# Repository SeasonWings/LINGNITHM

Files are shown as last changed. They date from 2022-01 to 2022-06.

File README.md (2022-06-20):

# LINGNITHM
个人记录向半开源CHUNITHM风格音乐游戏控制器

# 如果需要制作本控制器，你大体需要以下能力
* 完善的文件处理能力，可以阅读并看懂包括但不限于CAD，STP，Gerber等文件的作用
* 一定的单片机知识，能够识别和使用BootLoader和固件bin文件
* 一定的动手能力，能完成包括但不限于拧螺丝，贴片焊接，调试硬件等能力

# 控制器构成
* 控制器基于Arduino IDE，使用第三方的platfromIO编写固件程序
* 电路主控芯片使用了ATMEGA SAMD21G18A MCU，触摸IC使用了MPR121，AIR抬手感应使用了940MM红外对射灯珠
* 基本连接思路为 主控板-触摸板   主控板-AIR发射/接收转接器-HDMI线材-AIR发射/接收

如图所示
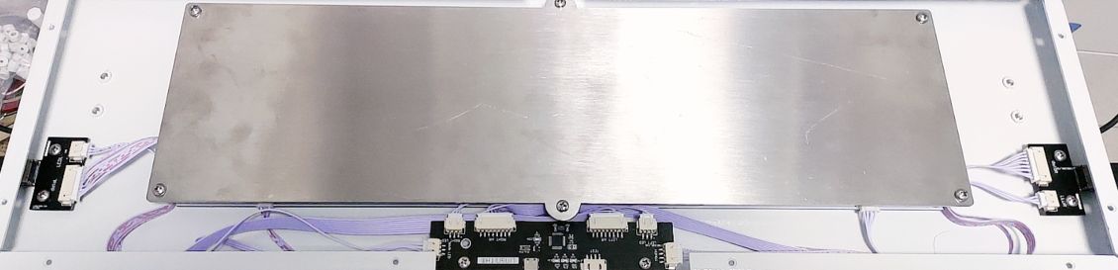
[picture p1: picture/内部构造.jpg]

                
* [固件方面](https://github.com/SeasonWings/LINGNITHM/tree/main/BootLoader%26Firmware) 有参考GSK，XPENG，ilufang，Sucareto等大佬的代码，在此特别提出感谢！！！
* 上传方面 你需要购买Jlink上传器，通过SEGGER软件向SAMD21上传固件以及BootLoader
* [物料方面](https://github.com/SeasonWings/LINGNITHM/blob/main/PCB%20Gerber%E5%88%B6%E7%89%88%E6%96%87%E4%BB%B61.1/PCB%E7%89%A9%E6%96%99BOM%E8%A1%A8.xlsx) 请在制作完PCB之后自行对照丝印(此句划掉，现在有了)

其余方面想到再补充(

# Update

#### 1.0更新
  * 脱胎换骨！现在你可以使用金属化的控制器外壳了！
  * 新的PCB设计改动以适配新的外壳。
  * 新的固件，包含直连协议(需要配合[修改后的chuniio和Segatools.ini](https://github.com/SeasonWings/LINGNITHM/tree/main/BootLoader%26Firmware/1.0%20Ver/chuniio%26Segatools "请务必将你的控制器设备放在COM1端口上！")使用),以及更加炫酷的灯光，更优的触摸算法。
  * 最新最热PCB物料BOM表已更新，感谢群友海腾的帮助！

#### 2.0更新
  * 通过上传新的固件&BootLoader来获得更新功能！
  * 键盘模式下新增设置接口，同时遮挡2，4，6号Air即可进入设置模式
  * 新增设置模式下的操作逻辑，稍后使用PDF文件进行说明
  * 现在你可以为你的键盘以及Air灯光效果自由编辑喜欢的灯光样式啦！

#### 3.0更新
  * LINGCON Setting的操作UI有部分变动
  * Setting进入逻辑修改，改变为全押Air

### 久违的更新（
#### 4.0更新
  * 代码触摸逻辑有大幅改动，现在触摸或许会更灵敏了(?)
  * Setting新增触摸校准（黄色按钮），把手指用你认为最小的力度划过触摸区来完成校准
  * 改变了新的上传Firmware方式，现在更加方便了,旧固件停止维护
  * 同时公开部分底层源代码，有能人士可以按自己所需添加想要的功能，详情见Source code

# License
CC
  * 你可以在遵循CC协议的条件下自由修改，查看，下载，使用本项目内文件
  * 禁止进行一切商业行为（“商业行为”指一切涉及本项目资金流动，包括但不限于：直接clone本项目文件 不经任何修改 拿来以任何方式出售或牟利的行为）
  * 最终解释权归本人所有
# 外观展示
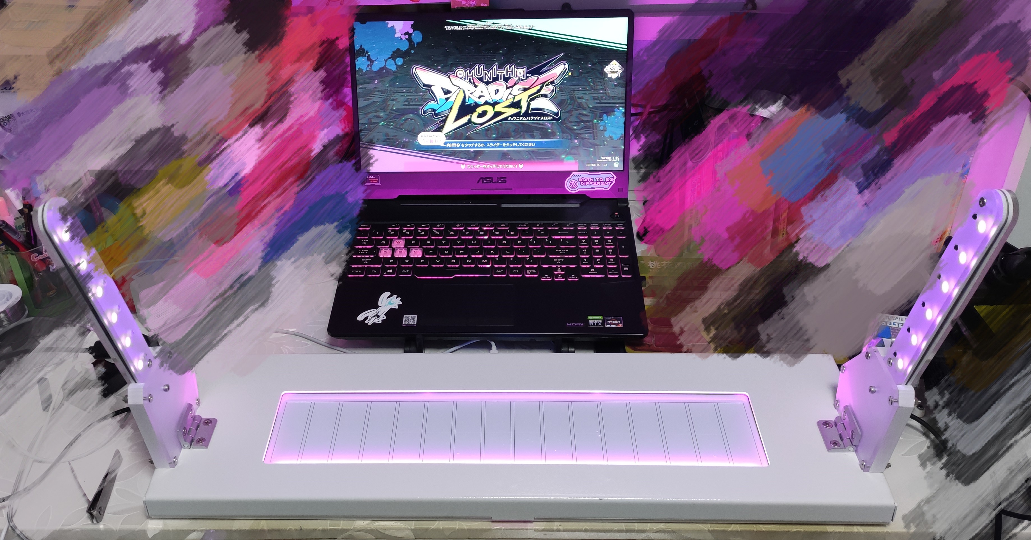
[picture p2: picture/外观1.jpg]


# 控制器使用展示
[点击这里！](https://www.bilibili.com/video/BV1Qm4y1Z7ms/ "你会给两个圆圆的硬币对么？")

如果觉得非常棒，可以给我一个一键三连么(

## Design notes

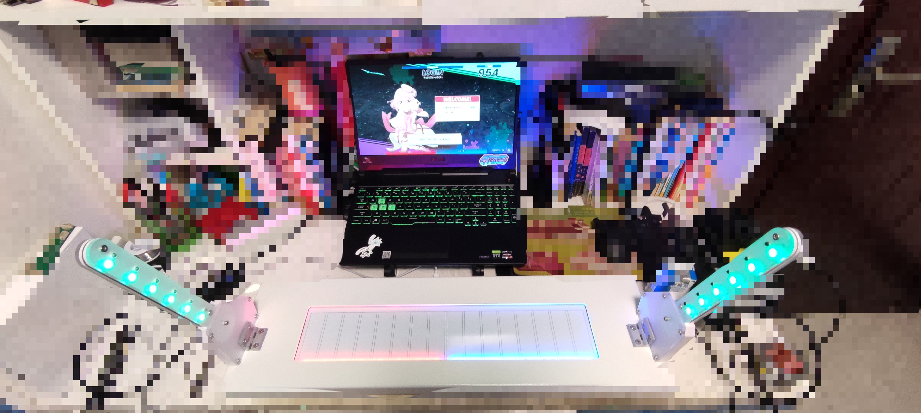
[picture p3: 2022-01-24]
picture/外观3.jpg

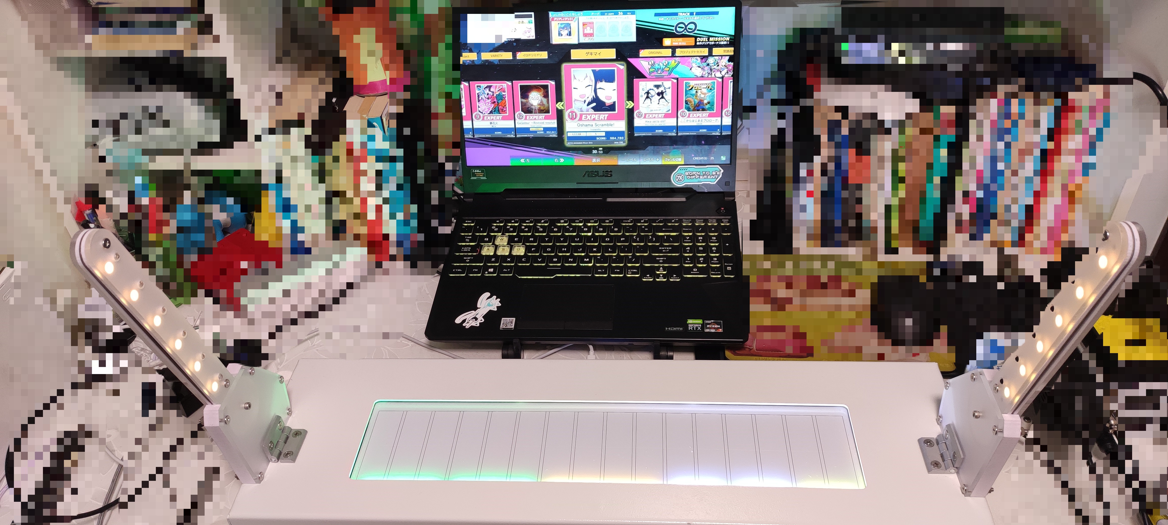
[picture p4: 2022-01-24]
picture/外观2.jpg

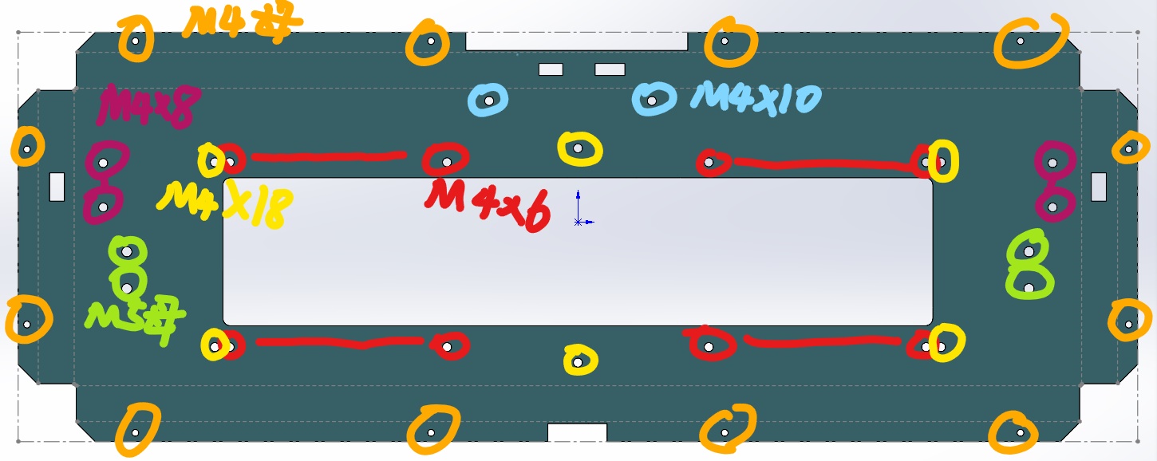
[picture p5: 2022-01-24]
钣金外壳/压铆工艺参数/mmexport1643044845670.jpg

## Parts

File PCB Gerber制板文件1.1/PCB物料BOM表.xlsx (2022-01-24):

主控板 |  |  | chuni触摸板 |  |  | CHUNI AIR 发射 |  |  | AIR发射转换器
器件名称(也许是) | 封装/参数 | 数量 | 器件名称(也许是) | 封装/参数 | 数量 | 器件名称(也许是) | 封装/参数 | 数量 | 器件名称(也许是) | 封装/参数 | 数量
SAM D21 | 48TQFP | 1 | MPR121QR2 | UQFN20 | 3 | 940mm红外发射 | LED-5mm-直插 | 6 | HDMI 卧式贴片 | 19P 4固定脚 | 1
AP2112K 3.3V稳压 | SOT-23-5 | 1 |  |  |  | N沟道MOS管2N7002 | SOT-23 | 6
32.768KHz晶振(12pf) | 3215 | 1 | 侧贴RGB(WS2812B) | 4020 | 31 | 3528反贴RGB(WS2812B) | 3528反贴(又名6028) | 6 | XH2.54 3P卧贴 | 3P 2贴片固定脚 | 1
12pF电容(晶振用) | 0603 | 2 |  |  |  | 0.1uF电容 | 0603 | 6 | XH2.54 8P卧贴 | 8P 2贴片固定脚 | 1
 |  |  | 0.1uF电容 | 0603 | 37 | 22R电阻 | 0603 | 6
0.1uF排容 | 0603*4 | 1
0.1uF电容 | 0603 | 4 | 10KΩ电阻 | 0603 | 5 | HDMI A型立式 母座 | 19P 3固定脚 | 1
1uF电容 | 0603 | 2 | 75KΩ 1%电阻 | 0603 | 3
 |  |  |  |  |  | CHUNI AIR 接收 |  |  | AIR接收转换器
1KΩ电阻 | 0603 | 4 | XH2.54 3P卧贴 | 3P 2贴片固定脚 | 1 | 器件名称(也许是) | 封装/参数 | 数量 | 器件名称(也许是) | 封装/参数 | 数量
10KΩ电阻 | 0603 | 1 | XH2.54 4P卧贴 | 4P 2贴片固定脚 | 1 | 940mm红外接收 | LED-5mm-直插 | 6 | HDMI 卧式贴片 | 19P 4固定脚 | 1
 |  |  |  |  |  | 3528反贴RGB(WS2812B)又名6028 | 3528反贴(又名6028) | 6
LED灯珠 | 0805 | 4 |  |  |  | 0.1uF电容 | 0603 | 6 | XH2.54 3P卧贴 | 3P 2贴片固定脚 | 1
 |  |  |  |  |  | 10KΩ电阻 | 0603 | 6 | XH2.54 8P卧贴 | 8P 2贴片固定脚 | 1
USB Type-C 卧贴 | 16P 4固定脚 | 1
XH2.54 3P卧贴 | 3P 2贴片固定脚 | 3 |  |  |  | HDMI A型立式 母座 | 19P 3固定脚 | 1
XH2.54 4P卧贴 | 4P 2贴片固定脚 | 2
XH2.54 8P卧贴 | 8P 2贴片固定脚 | 2
 |  |  |  |  |  | SeasonWings | 海腾 | Soar Duf | Soar Sea 最后更新时间:2021/1/25 2:28
总计
器件名称(也许是) | 封装/参数 | 数量
SAM D21 | 48TQFP | 1
AP2112K 3.3V稳压 | SOT-23-5 | 1
32.768KHz晶振(12pf) | 3215 | 1
12pF电容(晶振用) | 0603 | 2
0.1uF排容 | 0603*4 | 1
0.1uF电容 | 0603 | 53
1uF电容 | 0603 | 2
1KΩ电阻 | 0603 | 4
10KΩ电阻 | 0603 | 12
75KΩ 1%电阻 | 0603 | 3
LED灯珠 | 0805 | 4
MPR121QR2 | UQFN20 | 3
侧贴RGB(WS2812B) | 4020(也许是) | 31
3528反贴RGB(WS2812B) | 3528反贴(又名6028) | 12
N沟道MOS管2N7002 | SOT-23 | 6
22R电阻 | 0603 | 6
940nm红外发射管 | LED-5mm-直插 | 6
940mm红外接收管 | LED-5mm-直插 | 6
HDMI A型立式 母座 | 19P 3固定脚 | 2
HDMI 卧式贴片 | 19P 4固定脚 | 2
USB Type-C 卧贴 | 16P 4固定脚 | 1
XH2.54 3P卧贴 | 3P 2贴片固定脚 | 6
XH2.54 4P卧贴 | 4P 2贴片固定脚 | 3
XH2.54 8P卧贴 | 8P 2贴片固定脚 | 4

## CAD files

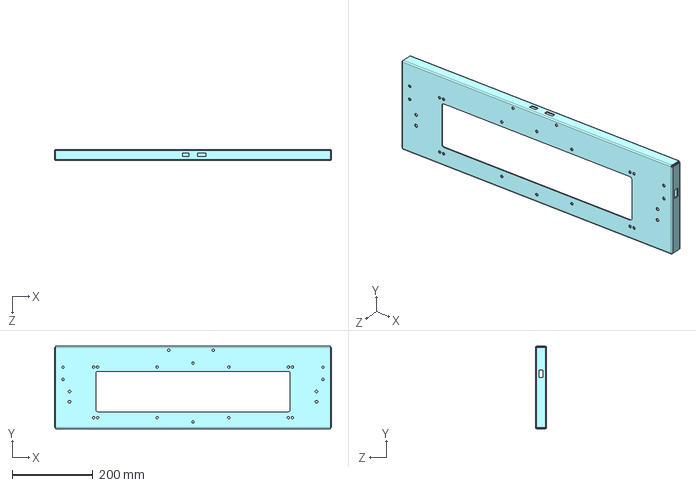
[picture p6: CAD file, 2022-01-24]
钣金外壳/钣金主体.STEP
684.0 x 204.0 x 27.0 mm

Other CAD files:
CAD结构件部分/304不锈钢盖板(2mm厚).dwg
CAD结构件部分/亚克力.dwg
CAD结构件部分/雪弗板.dwg

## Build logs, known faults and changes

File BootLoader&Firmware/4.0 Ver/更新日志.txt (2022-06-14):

#### 1.0更新
  * 脱胎换骨！现在你可以使用金属化的控制器外壳了！
  * 新的PCB设计改动以适配新的外壳。
  * 新的固件，包含直连协议(需要配合[修改后的chuniio和Segatools.ini](https://github.com/SeasonWings/LINGNITHM/tree/main/BootLoader%26Firmware/1.0%20Ver/chuniio%26Segatools "请务必将你的控制器设备放在COM1端口上！")使用),以及更加炫酷的灯光，更优的触摸算法。
  * 最新最热PCB物料BOM表已更新，感谢群友海腾的帮助！

#### 2.0更新
  * 键盘模式下新增设置接口，同时遮挡2，4，6号Air即可进入设置模式
  * 新增设置模式下的操作逻辑，稍后使用PDF文件进行说明
  * 现在你可以为你的键盘以及Air灯光效果自由编辑喜欢的灯光样式啦！

####3.0更新
  * LINGCON Setting的操作UI有部分变动
  * Setting进入逻辑修改，改变为全押Air

####4.0更新
  * 代码触摸逻辑有大幅改动，现在触摸或许会更灵敏了
  * Setting新增触摸校准（黄色按钮），用手指用你认为最小的力度划过触摸区来完成校准
  * 改变了新的上传Firmware方式，现在更加方便了
  * 同时公开部分底层源代码，有能人士可以按自己所需添加想要的功能

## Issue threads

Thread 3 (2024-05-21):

32.768KHz晶振(12pf) 这个是不是标错了

z748807622, 2024-05-21:
目前还没听说过哪家晶振工厂生产过标称负载电容CL为12pF的32.768KHz晶体谐振器。
                         --- https://www.genuway.com/5892.html

SeasonWings, 2024-05-21:
【淘宝】https://m.tb.cn/h.gdq8Dbz5Q3gkTW3?tk=hzdYWvTJrJz CZ8908 「3215贴片无源晶振 2脚 32.768KHZ 20PPM FC-135 6PF 9PF 12.5PF」实则12.5PF，EDA标12PF

Closed 2024-05-21.
